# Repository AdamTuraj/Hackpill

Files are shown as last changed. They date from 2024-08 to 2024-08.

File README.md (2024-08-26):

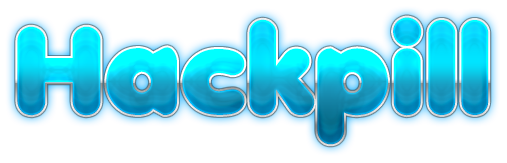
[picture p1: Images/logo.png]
Title Saying Hackpill
# 

**The Hackboard may be overkill, but Hackpill is here to fill the smaller shoes!**

The Hackpill is a small but versatile board at a small cost.

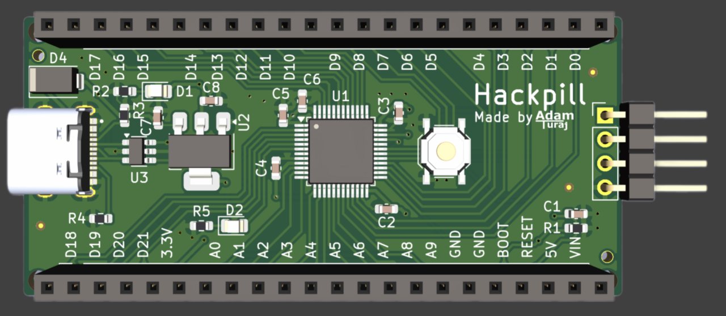
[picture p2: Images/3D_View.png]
A 3d view of the hackpill


Hackpill has the following features:

- 48MHz Cortex M0 Core with 32 Kb of Flash and 6 Kb of SRAM
- 32 GPIO pins
  - 1 SPI Interfaces
  - 1 I2C Interface
  - 1 CAN Interface
  - 1 USART Interface
  - 1 I2S Interface
  - 11 PWM Pins
  - 10 ADC's (Analog pins)
- An addressable LED
- USB C port for flashing and power

## Assembly

> [!CAUTION]
> The USBLC6 and diode may be orientated wrong. Ensure all components are properly orientated before ordering!

This board can be assembled through JLCPCB. The price for 5 assembled boards is around $35 USD without headers.

### Work with Arduino

> [!NOTE]
> You must have an STLink to continue. They can be bought standalone or with a Nucleo board.

A more detailed guide will be written up shortly. You may now use [STM32Duino](https://github.com/stm32duino/Arduino_Core_STM32) to make it work with Arduino.

## License

Hackclub is licensed under the MIT License. See the full license text in [LICENSE](LICENSE).

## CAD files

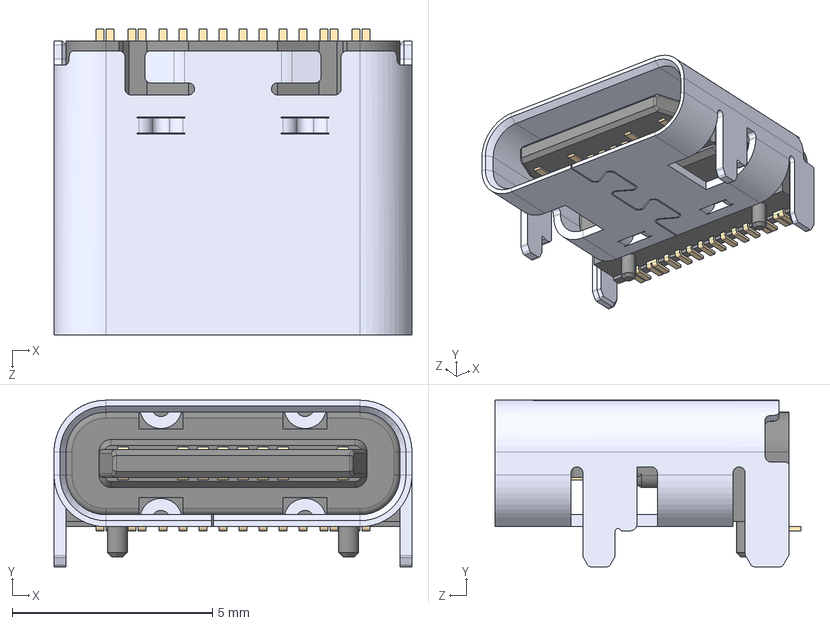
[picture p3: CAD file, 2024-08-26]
STEP/USB.step
8.94 x 4.16 x 7.65 mm

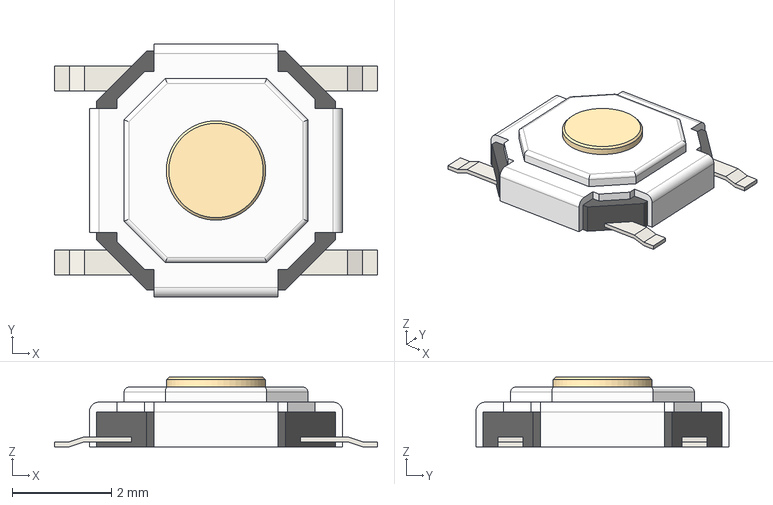
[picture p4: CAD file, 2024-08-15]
STEP/TS-1187A.step
6.50 x 5.10 x 1.40 mm

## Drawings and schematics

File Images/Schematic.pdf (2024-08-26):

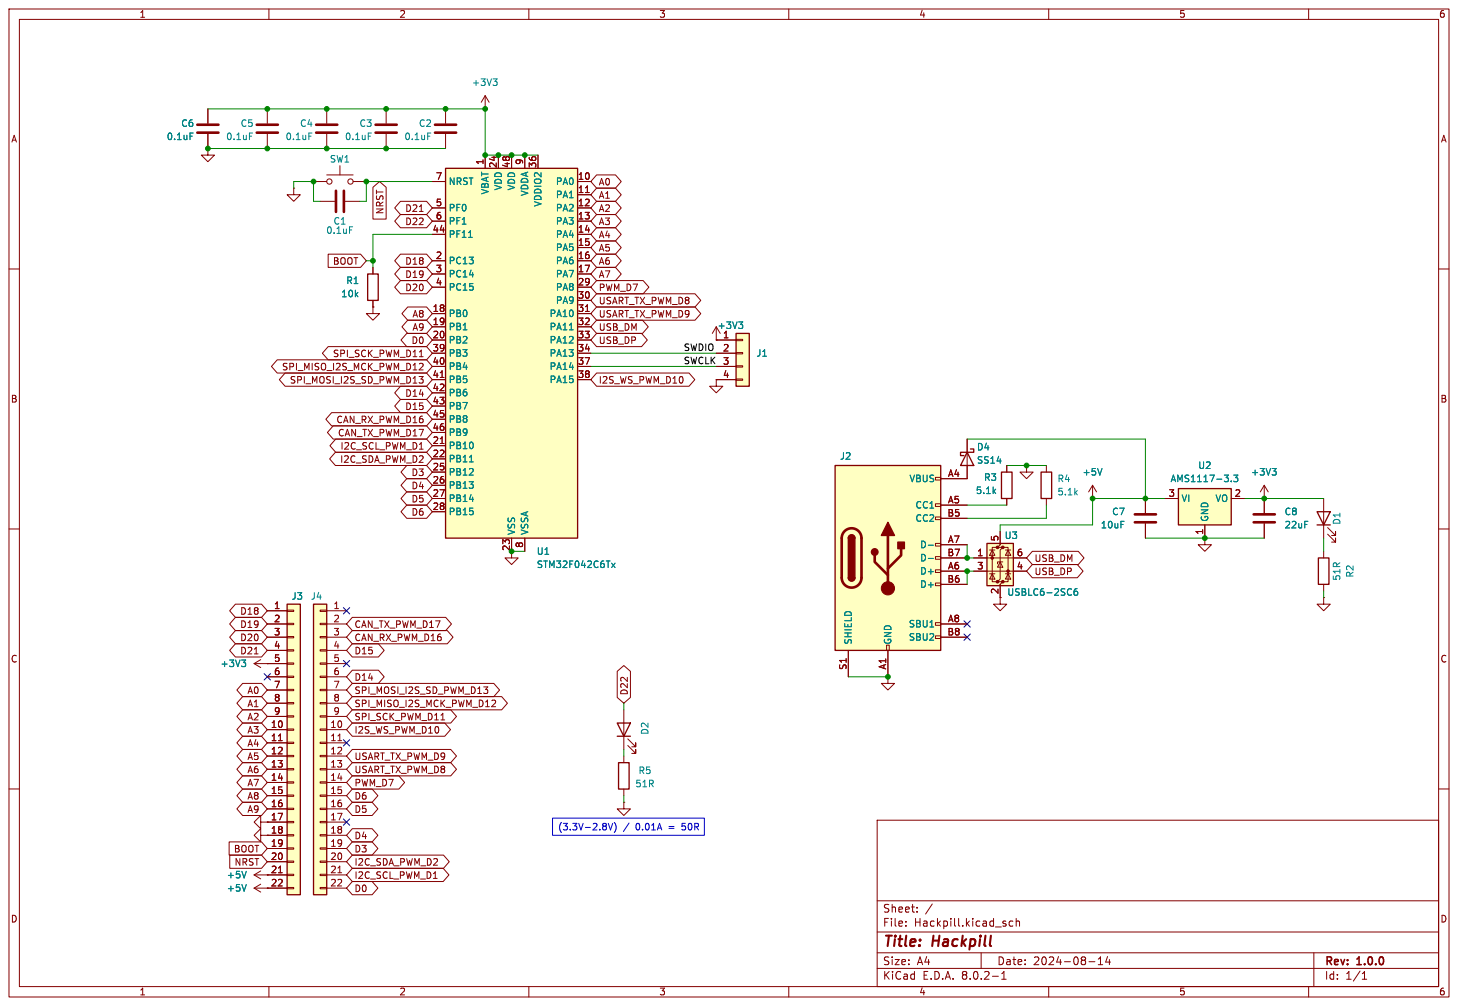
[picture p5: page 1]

Id: 1/1 Title: Hackpill File: Hackpill.kicad_sch Sheet: /

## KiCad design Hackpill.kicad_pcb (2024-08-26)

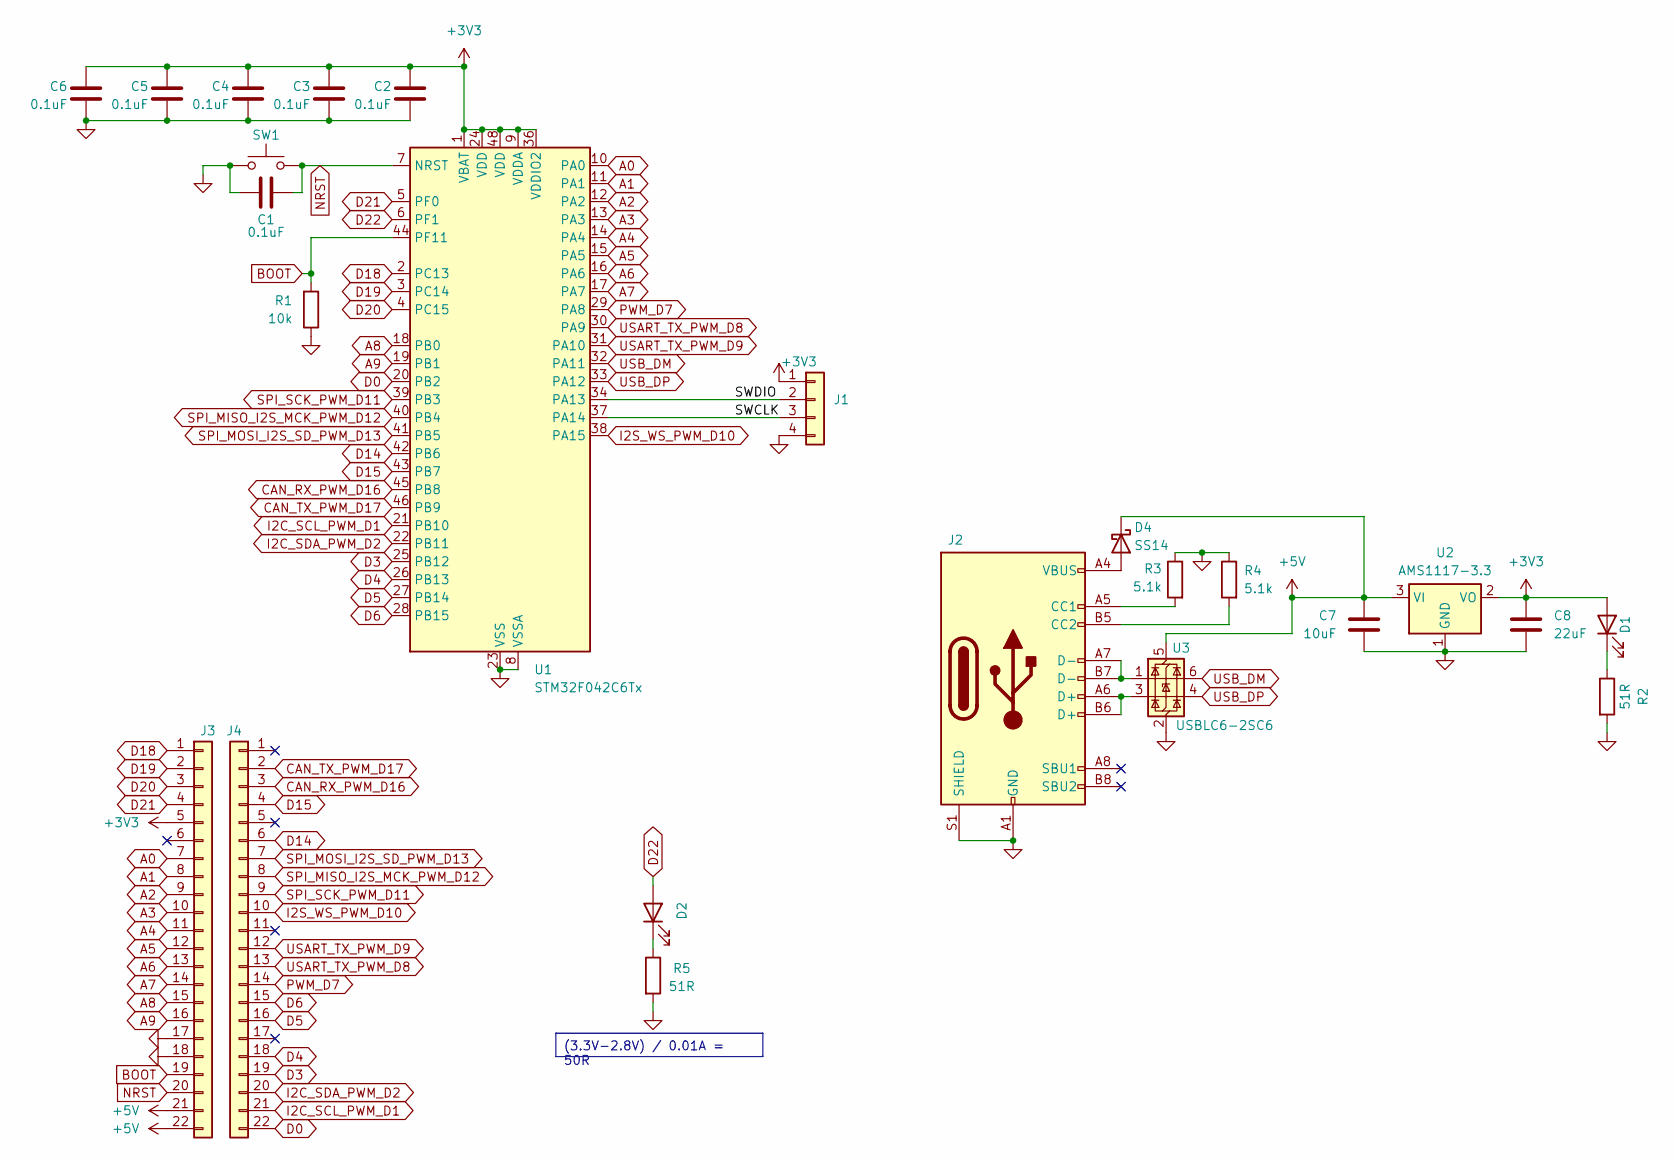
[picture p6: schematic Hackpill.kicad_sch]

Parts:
C1, C2, C3, C4, C5, C6: 0.1uF; C_0603_1608Metric
C7: 10uF; C_0603_1608Metric
C8: 22uF; C_0603_1608Metric
D1, D2: LED; LED_0805_2012Metric; LCSC C2297
D4: SS14; D_SMA
J1: Conn_01x04; PinHeader_1x04_P2.54mm_Vertical; LCSC C18905864
J2: USB_C_Receptacle_USB2.0_16P; USB_C_Receptacle_Shouhan_16P_TopMnt_Horizontal; LCSC C6332269
J3: Conn_01x22; PinSocket_1x22_P2.54mm_Vertical
J4: Conn_01x22; PinSocket_1x22_P2.54mm_Vertical; LCSC C18078140
R1: 10k; R_0603_1608Metric
R2, R5: 51R; R_0603_1608Metric
R3, R4: 5.1k; R_0603_1608Metric
SW1: SW_Push; SW_Push_1P1T_XKB_TS-1187A; LCSC C318884
U1: STM32F042C6Tx; LQFP-48_7x7mm_P0.5mm; LCSC C88447
U2: AMS1117-3.3; SOT-223-3_TabPin2; LCSC C6186
U3: USBLC6-2SC6; SOT-23-6; LCSC C2827654

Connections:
+3V3: C2.1, C3.1, C4.1, C5.1, C6.1, C8.1, D1.2 (A), J1.1, J3.5, U1.1 (VBAT), U1.9 (VDDA), U1.24 (VDD), U1.36 (VDDIO2), U1.48 (VDD), U2.2 (VO)
+5V: C7.1, D4.1 (K), J3.21, J3.22, U2.3 (VI), U3.5 (VBUS)
/SWCLK: J1.3, U1.37 (PA14)
/SWDIO: J1.2, U1.34 (PA13)
A0: J3.7, U1.10 (PA0)
A1: J3.8, U1.11 (PA1)
A2: J3.9, U1.12 (PA2)
A3: J3.10, U1.13 (PA3)
A4: J3.11, U1.14 (PA4)
A5: J3.12, U1.15 (PA5)
A6: J3.13, U1.16 (PA6)
A7: J3.14, U1.17 (PA7)
A8: J3.15, U1.18 (PB0)
A9: J3.16, U1.19 (PB1)
BOOT: J3.19, R1.2, U1.44 (PF11)
CAN_RX_PWM_D16: J4.3, U1.45 (PB8)
CAN_TX_PWM_D17: J4.2, U1.46 (PB9)
D0: J4.22, U1.20 (PB2)
D3: J4.19, U1.25 (PB12)
D4: J4.18, U1.26 (PB13)
D5: J4.16, U1.27 (PB14)
D6: J4.15, U1.28 (PB15)
D14: J4.6, U1.42 (PB6)
D15: J4.4, U1.43 (PB7)
D18: J3.1, U1.2 (PC13)
D19: J3.2, U1.3 (PC14)
D20: J3.3, U1.4 (PC15)
D21: J3.4, U1.5 (PF0)
D22: D2.2 (A), U1.6 (PF1)
GND: C1.1, C2.2, C3.2, C4.2, C5.2, C6.2, C7.2, C8.2, J1.4, J2.A1 (GND), J2.A12 (GND), J2.B1 (GND), J2.B12 (GND), J2.S1 (SHIELD), J3.17, J3.18, R1.1, R2.2, R3.1, R4.1, R5.2, SW1.1, U1.8 (VSSA), U1.23 (VSS), U1.35 (VSS), U1.47 (VSS), U2.1 (GND), U3.2 (GND)
I2C_SCL_PWM_D1: J4.21, U1.21 (PB10)
I2C_SDA_PWM_D2: J4.20, U1.22 (PB11)
I2S_WS_PWM_D10: J4.10, U1.38 (PA15)
NRST: C1.2, J3.20, SW1.2, U1.7 (NRST)
unnamed: D1.1 (K), R2.1
unnamed: D2.1 (K), R5.1
unnamed: D4.2 (A), J2.A4 (VBUS), J2.A9 (VBUS), J2.B4 (VBUS), J2.B9 (VBUS)
unnamed: J2.A5 (CC1), R3.2
unnamed: J2.B5 (CC2), R4.2
unnamed: J2.A6 (D+), J2.B6 (D+), U3.3 (I/O2)
unnamed: J2.A7 (D-), J2.B7 (D-), U3.1 (I/O1)
PWM_D7: J4.14, U1.29 (PA8)
SPI_MISO_I2S_MCK_PWM_D12: J4.8, U1.40 (PB4)
SPI_MOSI_I2S_SD_PWM_D13: J4.7, U1.41 (PB5)
SPI_SCK_PWM_D11: J4.9, U1.39 (PB3)
USART_TX_PWM_D8: J4.13, U1.30 (PA9)
USART_TX_PWM_D9: J4.12, U1.31 (PA10)
USB_DM: U1.32 (PA11), U3.6 (I/O1)
USB_DP: U1.33 (PA12), U3.4 (I/O2)

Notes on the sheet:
(3.3V-2.8V) / 0.01A = 50R

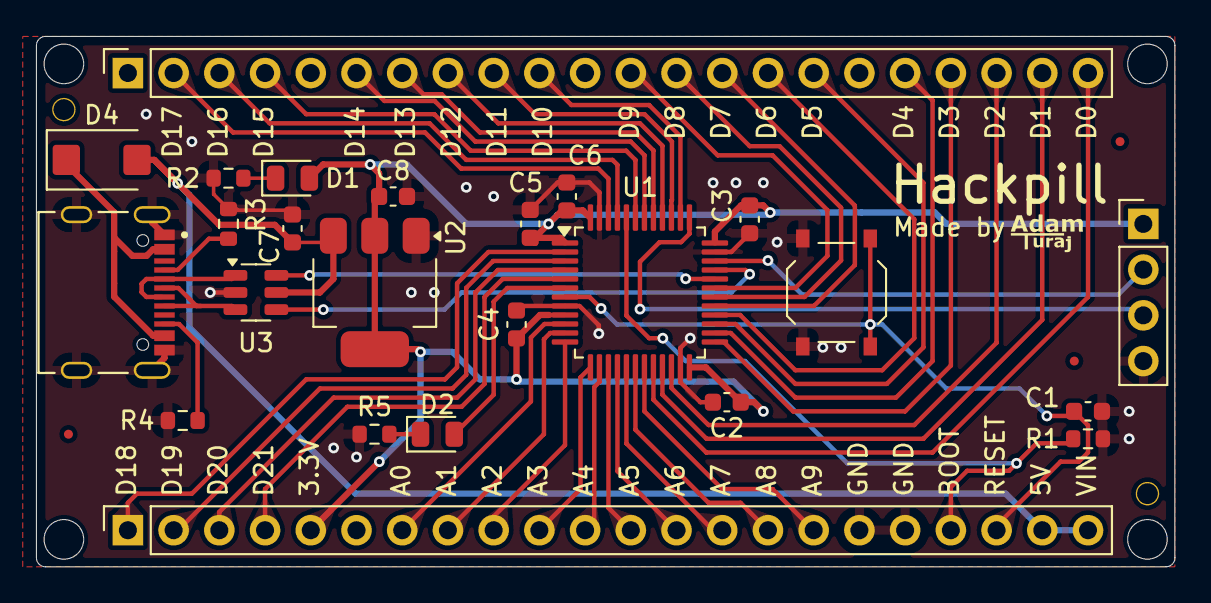
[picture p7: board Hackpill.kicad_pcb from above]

Board: 2 copper layers, 63.2 x 29.5 mm, 24 parts (0 on the bottom side), 49 nets.

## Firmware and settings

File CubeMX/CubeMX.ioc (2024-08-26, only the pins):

Mcu.UserName=STM32F042C6Tx
PA0.GPIO_Label=A9
PA0.Signal=ADC_IN0
PA1.GPIO_Label=A8
PA1.Signal=ADC_IN1
PA10.GPIO_Label=USART_RX_PWM_D9
PA10.Signal=S_TIM1_CH3
PA11.GPIO_Label=USB_DM
PA11.Signal=USB_DM
PA12.GPIO_Label=USB_DP
PA12.Signal=USB_DP
PA13.Signal=SYS_SWDIO
PA14.Signal=SYS_SWCLK
PA15.GPIO_Label=I2S_WS_PWM_D10
PA15.Signal=S_TIM2_CH1_ETR
PA2.GPIO_Label=A7
PA2.Signal=ADC_IN2
PA3.GPIO_Label=A6
PA3.Signal=ADC_IN3
PA4.GPIO_Label=A5
PA4.Signal=ADC_IN4
PA5.GPIO_Label=A4
PA5.Signal=ADC_IN5
PA6.GPIO_Label=A3
PA6.Signal=ADC_IN6
PA7.GPIO_Label=A2
PA7.Signal=ADC_IN7
PA8.GPIO_Label=PWM_D7
PA8.Signal=S_TIM1_CH1
PA9.GPIO_Label=USART_TX_PWM_D8
PA9.Signal=S_TIM1_CH2
PB0.GPIO_Label=A1
PB0.Signal=ADC_IN8
PB1.GPIO_Label=A0
PB1.Signal=ADC_IN9
PB10.GPIO_Label=I2C_SCL_PWM_D1
PB10.Signal=S_TIM2_CH3
PB11.GPIO_Label=I2C_SDA_PWM_D2
PB11.Signal=S_TIM2_CH4
PB12.GPIO_Label=D3
PB12.Signal=GPIO_Input
PB13.GPIO_Label=D4
PB13.Signal=GPIO_Input
PB14.GPIO_Label=D5
PB14.Signal=GPIO_Input
PB15.GPIO_Label=D6
PB15.Signal=GPIO_Input
PB2.GPIO_Label=D0
PB2.Signal=GPIO_Input
PB3.GPIO_Label=SPI_SCK_PWM_D11
PB3.Signal=S_TIM2_CH2
PB4.GPIO_Label=SPI_MISO_I2S_MCK_PWM_D12
PB4.Signal=S_TIM3_CH1
PB5.GPIO_Label=SPI_MOSI_I2S_SD_PWM_D13
PB5.Signal=S_TIM3_CH2
PB6.GPIO_Label=D14
PB6.Signal=GPIO_Input
PB7.GPIO_Label=D15
PB7.Signal=GPIO_Input
PB8.GPIO_Label=CAN_RX_PWM_D16
PB8.Signal=S_TIM16_CH1
PB9.GPIO_Label=CAN_TX_PWM_D17
PB9.Signal=S_TIM17_CH1
PC13.GPIO_Label=D18
PC13.Signal=GPIO_Input
PC14OSC32_IN.GPIO_Label=D19
PC14OSC32_IN.Signal=GPIO_Input
PC15OSC32_OUT.GPIO_Label=D20
PC15OSC32_OUT.Signal=GPIO_Input
PF0-OSC_IN.GPIO_Label=D21
PF0-OSC_IN.Signal=GPIO_Input
PF1-OSC_OUT.GPIO_Label=D22
PF1-OSC_OUT.Signal=GPIO_Input
PF11.GPIO_Label=BOOT
PF11.Signal=GPIO_Input

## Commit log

2024-08-15 First commit!
    [Workshop_PCB.kicad_pcb, Workshop_PCB.kicad_sch]
2024-08-15 Finish schematic, assign components and footprints
    [Workshop_PCB.kicad_pcb, Workshop_PCB.kicad_sch]
2024-08-15 Finish component selection and footprint assignment
    [Workshop_PCB.kicad_pcb, Workshop_PCB.kicad_sch]
2024-08-15 Start tracing board
    [Workshop_PCB.kicad_pcb, Workshop_PCB.kicad_sch]
2024-08-15 Finish PCB
    [TS-1187A.step, Workshop_PCB.kicad_pcb, Workshop_PCB.kicad_sch]
2024-08-16 Adjust trace width, adjust pinout, make changes to schematic
    [Workshop_PCB.kicad_pcb, Workshop_PCB.kicad_sch]
2024-08-16 Complete fixes for PCB
    [Workshop_PCB.kicad_pcb, Workshop_PCB.kicad_sch]
2024-08-16 Add diode to USB, rename files, add prod files
    [Hackpill.kicad_pcb, Hackpill.kicad_sch]
2024-08-26 Change clearence, update footprint, add README, add schematic, remove config file
    [Hackpill.kicad_pcb, Hackpill.kicad_sch, USB.step]
